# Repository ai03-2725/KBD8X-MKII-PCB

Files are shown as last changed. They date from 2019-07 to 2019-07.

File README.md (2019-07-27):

# KBD8X-MKII-PCB
This is the source for the PCB used in the [KBD8X MKII by KBDfans](https://kbdfans.com/collections/kbd8x-mkii/products/coming-soon-kbd8x-mkii-custom-mechanical-keyboard-kit).  

Please verify the conditions of the [license](https://github.com/ai03-2725/KBD8X-MKII-PCB/blob/master/LICENSE) before using.

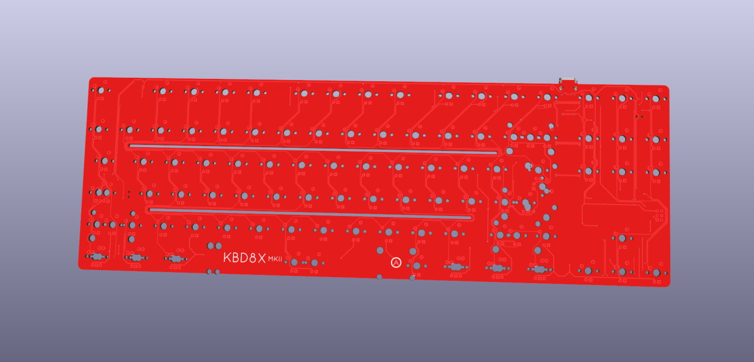
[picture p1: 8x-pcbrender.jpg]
render


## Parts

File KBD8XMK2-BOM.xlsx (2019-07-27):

Component | Description | Part | References | Value | Footprint | Quantity Per PCB
1 | Capacitor, Ceramic, 0603, ≥15V | C_Small | C6 C7 C8 CRGB1 CRGB2 CRGB3 CRGB4 CRGB5 CRGB6 CRGB7 CRGB8 CRGB9 CRGB10 CRGB11 CRGB12 CRGB13 CRGB14 CRGB15 CRGB16 CRGB17 CRGB18 | 0.1uF | C_0603 | 21
2 | Capacitor, Ceramic, 0603, ≥15V | C_Small | C5 | 10uF | C_0603 | 1
3 | Capacitor, Ceramic, 0603, ≥15V | C_Small | C2 | 1uF | C_0603 | 1
4 | Capacitor, Ceramic, 0603, ≥15V | C_Small | C3 C4 | 22pF | C_0603 | 2
5 | Diode, Generic, SOD-123 | D_Small | D1 D2 D3 D4 D5 D6 D7 D8 D9 D10 D11 D12 D13 D14 D17 D18 D19 D20 D21 D22 D23 D24 D25 D26 D27 D28 D29 D30 D31 D35 D36 D37 D38 D39 D40 D41 D42 D43 D44 D45 D46 D47 D48 D52 D53 D54 D55 D56 D57 D58 D59 D60 D61 D62 D63 D65 D66 D67 D68 D69 D70 D71 D72 D73 D74 D75 D76 D77 D78 D81 D82 D84 D85 D86 D87 D90 D91 D92 D93 D94 D95 D96 D97 D99 D100 D101 D108 D111 D112 D113 | SOD-323 | D_SOD-123 | 90
6 | Polyfuse, 1206, 500mA Hold, 1A Trip, ≥15V | Polyfuse_Small | F1 | 500mA | Fuse_SMD1206_Wave | 1
7 | NPN transistor, DSS60601MZ4-13, SOT-223 | Q_NPN_BCE | Q1 | DSS60601MZ4-13 | SOT-223-3_TabPin2 | 1
8 | Resistor, Generic, 0603 | R_Small | R1 R2 R3 R4 R5 R6 R7 R8 R9 R10 R11 R12 R13 R14 R16 R17 R18 R19 R20 R21 R22 R23 R24 R25 R26 R27 R28 R29 R30 R31 R32 R33 R35 R36 R37 R38 R39 R40 R41 R42 R43 R44 R45 R46 R47 R48 R52 R53 R54 R55 R56 R57 R58 R59 R60 R61 R62 R63 R65 R66 R67 R68 R69 R70 R71 R72 R73 R74 R75 R76 R77 R78 R81 R82 R84 R85 R86 R87 R90 R91 R95 R96 R97 R99 R100 R101 R108 R111 R112 R113 RC4 | 1k | R_0603 | 91
9 | Resistor, Generic, 0603 | R_Small | RC5 | 1.5k | R_0603 | 1
10 | Resistor, Generic, 0603 | R_Small | RC3 | 10k | R_0603 | 1
11 | Resistor, Generic, 0603 | R_Small | RC1 RC2 | 22 | R_0603 | 2
12 | Resistor, Generic, 0603 | R_Small | RC6 RC7 | 5k1 | R_0603 | 2
13 | RGB LED, WS2812B, 5050 | WS2812B | RGB1 RGB2 RGB3 RGB4 RGB5 RGB6 RGB7 RGB8 RGB9 RGB10 RGB11 RGB12 RGB13 RGB14 RGB15 RGB16 RGB17 RGB18 | WS2812B | LED_WS2812B-PLCC4 | 18
14 | Push button, 5.2 x 5.2mm | SW_Push | SW1 | SW_Push | SKQG-1155865 | 1
15 | Switch, SPDT, PCM12 | SW_SPDT | SW2 SW3 | SW_SPDT | SW_SPDT_PCM12 | 2
16 | ATmega32U4-MU | ATmega32U4-MU | U1 | ATmega32U4-MU | QFN-44-1EP_7x7mm_Pitch0.5mm | 1
17 | ESD Protection IC, PRTR5V0U2X,215 | PRTR5V0U2X | U2 | PRTR5V0U2X | SOT143B | 1
18 | USB Type-C Connector, HRO TYPE-C-31-M-12 | HRO-TYPE-C-31-M-12 | USB1 | HRO-TYPE-C-31-M-12 | HRO-TYPE-C-31-M-12-Assembly | 1
19 | Crystal, 3.2 x 2.5mm, 16MHz | Crystal_GND24 | Y1 | 16MHz | Crystal_SMD_3225-4pin_3.2x2.5mm | 1
Component Groups: | 19
Component Count: | 239
Fitted Components: | 239
Number of PCBs: | 1
Total components: | 239
Schematic Version:
Schematic Date:
BoM Date: | 2019-04-04 15:30
Schematic Source:
KiCad Version: | Eeschema (5.0.2)-1

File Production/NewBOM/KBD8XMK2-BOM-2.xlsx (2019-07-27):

Comment | Description | Designator | Footprint | Pins | Quantity
0.1uF 20% ≥15V X5R/X7R | Capacitor, Ceramic, 0603 | C6 C7 C8 CRGB1 CRGB2 CRGB3 CRGB4 CRGB5 CRGB6 CRGB7 CRGB8 CRGB9 CRGB10 CRGB11 CRGB12 CRGB13 CRGB14 CRGB15 CRGB16 CRGB17 CRGB18 | C_0603 | 2 | 21
10uF 20% ≥15V X5R/X7R | Capacitor, Ceramic, 0603 | C5 | C_0603 | 2 | 1
1uF 20% ≥15V X5R/X7R | Capacitor, Ceramic, 0603 | C2 | C_0603 | 2 | 1
22pF 5% ≥15V C0G | Capacitor, Ceramic, 0603 | C3 C4 | C_0603 | 2 | 2
Generic | Diode, SOD-123 | D1 D2 D3 D4 D5 D6 D7 D8 D9 D10 D11 D12 D13 D14 D17 D18 D19 D20 D21 D22 D23 D24 D25 D26 D27 D28 D29 D30 D31 D35 D36 D37 D38 D39 D40 D41 D42 D43 D44 D45 D46 D47 D48 D52 D53 D54 D55 D56 D57 D58 D59 D60 D61 D62 D63 D65 D66 D67 D68 D69 D70 D71 D72 D73 D74 D75 D76 D77 D78 D81 D82 D84 D85 D86 D87 D90 D91 D92 D93 D94 D95 D96 D97 D99 D100 D101 D108 D111 D112 D113 | D_SOD-123 | 2 | 90
500mA ≥15V 500mA_Hold 1A_Trip | Polyfuse, 1206 | F1 | Fuse_SMD1206_Wave | 2 | 1
DSS60601MZ4-13 | NPN transistor, SOT-223 | Q1 | SOT-223-3_TabPin2 | 4 | 1
1k 1% | Resistor, Generic, 0603 | R1 R2 R3 R4 R5 R6 R7 R8 R9 R10 R11 R12 R13 R14 R16 R17 R18 R19 R20 R21 R22 R23 R24 R25 R26 R27 R28 R29 R30 R31 R32 R33 R35 R36 R37 R38 R39 R40 R41 R42 R43 R44 R45 R46 R47 R48 R52 R53 R54 R55 R56 R57 R58 R59 R60 R61 R62 R63 R65 R66 R67 R68 R69 R70 R71 R72 R73 R74 R75 R76 R77 R78 R81 R82 R84 R85 R86 R87 R90 R91 R95 R96 R97 R99 R100 R101 R108 R111 R112 R113 RC4 | R_0603 | 2 | 91
1.5k 1% | Resistor, Generic, 0603 | RC5 | R_0603 | 2 | 1
10k 1% | Resistor, Generic, 0603 | RC3 | R_0603 | 2 | 1
22 1% | Resistor, Generic, 0603 | RC1 RC2 | R_0603 | 2 | 2
5.1k 1% | Resistor, Generic, 0603 | RC6 RC7 | R_0603 | 2 | 2
WS2812B | RGB LED, 5050 | RGB1 RGB2 RGB3 RGB4 RGB5 RGB6 RGB7 RGB8 RGB9 RGB10 RGB11 RGB12 RGB13 RGB14 RGB15 RGB16 RGB17 RGB18 | LED_WS2812B-PLCC4 | 4 | 18
SMT 5.2 x 5.2 x 1.5mm | Push button | SW1 | SKQG-1155865 | 4 | 1
SPDT PCM12 | Switch, SPDT | SW2 SW3 | SW_SPDT_PCM12 | 7 | 2
ATmega32U4-MU | ATmega32U4-MU | U1 | QFN-44-1EP_7x7mm_Pitch0.5mm | 45 | 1
PRTR5V0U2X | ESD Protection IC | U2 | SOT143B | 4 | 1
HRO-TYPE-C-31-M-12 | USB Type-C Connector | USB1 | HRO-TYPE-C-31-M-12-Assembly | 16 | 1
16MHz | Crystal, 3.2 x 2.5mm (3225-4) | Y1 | Crystal_SMD_3225-4pin_3.2x2.5mm | 4 | 1

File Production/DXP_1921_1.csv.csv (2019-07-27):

Comment | Description | Designator | Footprint | Pins | Quantity
10nF (103) 10% 50V | 贴片电容 | C1, C2, C3, C4, C5, C6, C7 | LC-0603_C | 2 | 7
1.5nF (152) 10% 50V | 贴片电容 | C8, C9, C10, C11, C22, C23, C31, C32, C34, C35, C36, C37, C38, C39, C40 | LC-0805_C | 2 | 15
100nF (104) ±10% 16V | 贴片电容 | C67, C68, C69, C70, C71, C72, C73, C74, C75, C76, C77, C78, C79, C80, C81, C82, C83, C84, C85, C86, C87, C88, C89, C90, C91, C92, C93, C94, C95, C96, C97, C98, C99, C100, C101, C102, C103, C104, C105, C106, C107 | LC-0402_C | 2 | 41
4.7uH ±10% | 贴片电感 | L1, L4 | LC-0603_L | 2 | 2
47nH | 贴片电感 | L2 | LC-0603_L | 2 | 1
68nH ±5% 0603 | 贴片电感 | L3 | LC-0603_L | 2 | 1
10nH ±5% | 贴片电感 | L16, L17, L18, L19, L20, L21, L22, L23, L24, L25, L26, L27 | LC-0402_L | 2 | 12
22nH ±5% | 贴片电感 | L31 | LC-0603_L | 2 | 1
13KΩ (1302) ±1% | 贴片电阻 | R5, R6, R7, R8, R9, R10, R11, R12, R13, R14, R15, R16, R17, R18, R19, R21, R31, R41, R51, R61 | LC-0603_R | 2 | 20
300Ω (3000) ±1% | 贴片电阻 | R192, R193, R194, R195, R196, R200, R201, R202, R203, R204, R205, R206, R207, R208, R209, R210, R211, R212, R213, R214, R215, R216, R217, R218, R219, R220, R221, R222, R223, R224, R225, R226, R227, R228, R229, R230, R231, R232, R233, R234, R235, R236, R237, R238, R239, R240, R241, R242, R243, R244, R245, R246, R247, R248, R249, R250, R251, R252, R253, R254 | LC-0402_R | 2 | 60

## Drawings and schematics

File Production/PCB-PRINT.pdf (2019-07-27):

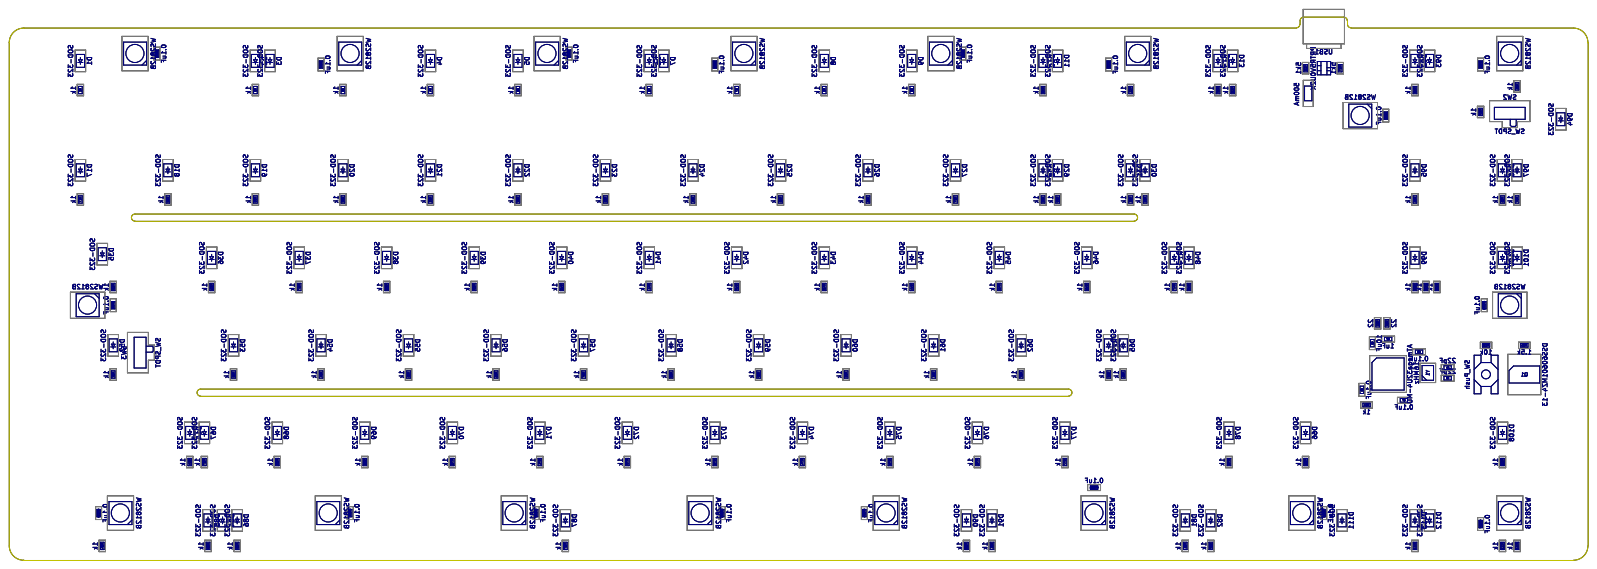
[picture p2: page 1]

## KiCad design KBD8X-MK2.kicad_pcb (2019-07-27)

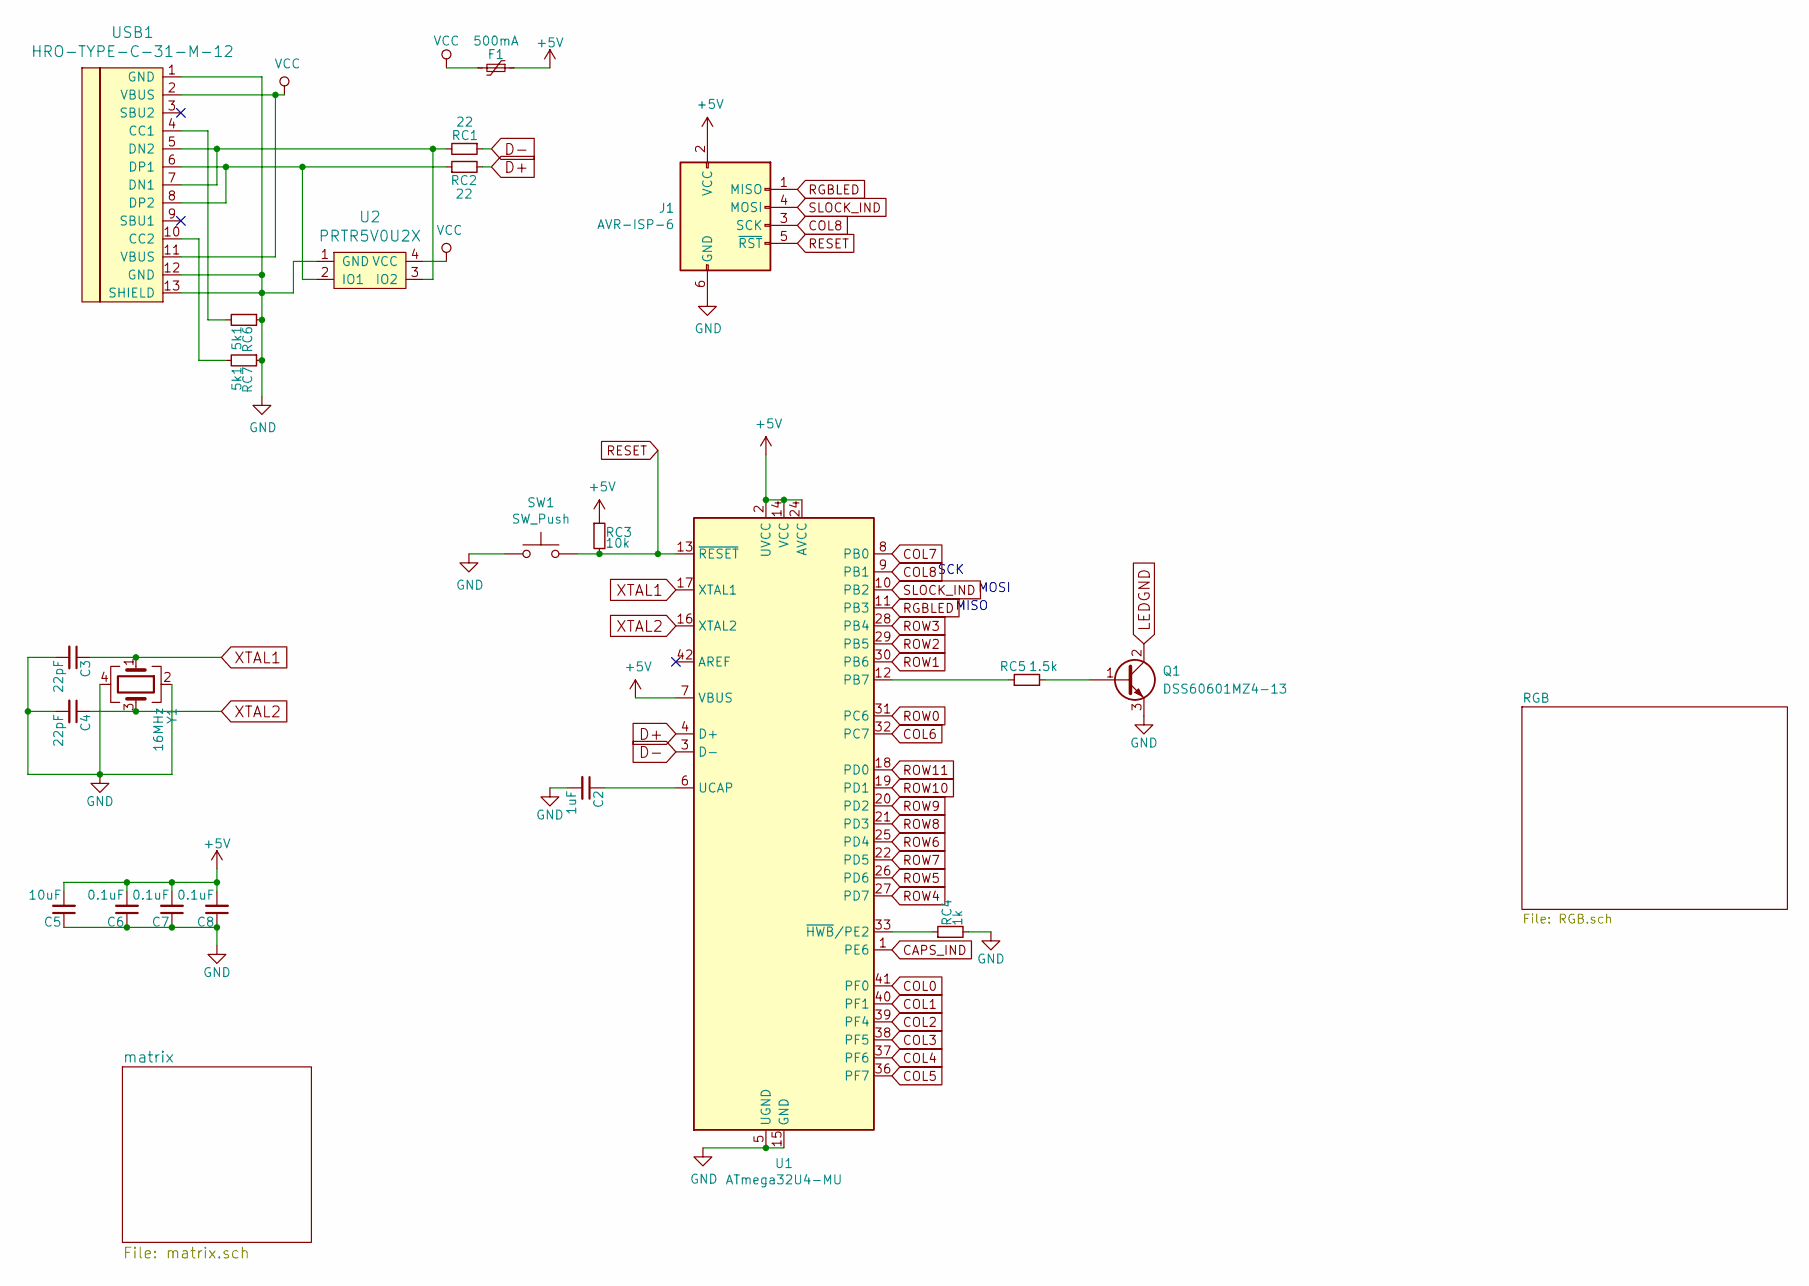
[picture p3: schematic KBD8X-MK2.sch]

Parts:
C2: 1uF; C_0603
C3, C4: 22pF; C_0603
C5: 10uF; C_0603
C6, C7, C8: 0.1uF; C_0603
F1: 500mA; Fuse_SMD1206_Wave
J1: AVR-ISP-6; Reset_Pretty-Mask
Q1: DSS60601MZ4-13; SOT-223-3_TabPin2
RC1, RC2: 22; R_0603
RC3: 10k; R_0603
RC4: 1k; R_0603
RC5: 1.5k; R_0603
RC6, RC7: 5k1; R_0603
SW1: SW_Push; SKQG-1155865
U1: ATmega32U4-MU; QFN-44-1EP_7x7mm_Pitch0.5mm
U2: PRTR5V0U2X; SOT143B
USB1: HRO-TYPE-C-31-M-12; HRO-TYPE-C-31-M-12-Assembly
Y1: 16MHz; Crystal_SMD_3225-4pin_3.2x2.5mm

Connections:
+5V: C5.2, C6.2, C7.2, C8.2, F1.1, J1.2 (VCC), RC3.1, U1.2 (UVCC), U1.7 (VBUS), U1.14 (VCC), U1.24 (AVCC), U1.34 (VCC), U1.44 (AVCC); also elsewhere on the board
CAPS_IND: U1.1 (PE6); also elsewhere on the board
COL0: U1.41 (PF0); also elsewhere on the board
COL1: U1.40 (PF1); also elsewhere on the board
COL2: U1.39 (PF4); also elsewhere on the board
COL3: U1.38 (PF5); also elsewhere on the board
COL4: U1.37 (PF6); also elsewhere on the board
COL5: U1.36 (PF7); also elsewhere on the board
COL6: U1.32 (PC7); also elsewhere on the board
COL7: U1.8 (PB0); also elsewhere on the board
COL8: J1.3 (SCK), U1.9 (PB1); also elsewhere on the board
D+: RC2.2, U1.4 (D+)
D-: RC1.1, U1.3 (D-)
GND: C2.2, C3.2, C4.2, C5.1, C6.1, C7.1, C8.1, J1.6 (GND), Q1.3 (E), RC4.2, RC6.1, RC7.1, SW1.1, U1.5 (UGND), U1.15 (GND), U1.23 (GND), U1.35 (GND), U1.43 (GND), U1.45 (GND), U2.1 (GND), USB1.1 (GND), USB1.12 (GND), USB1.13 (SHIELD), Y1.2, Y1.4; also elsewhere on the board
LEDGND: Q1.2 (C); also elsewhere on the board
unnamed: C2.1, U1.6 (UCAP)
unnamed: Q1.1 (B), RC5.2
unnamed: RC1.2, U2.3 (IO2), USB1.5 (DN2), USB1.7 (DN1)
unnamed: RC2.1, U2.2 (IO1), USB1.6 (DP1), USB1.8 (DP2)
unnamed: RC4.1, U1.33 (~HWB~/PE2)
unnamed: RC5.1, U1.12 (PB7)
unnamed: RC6.2, USB1.4 (CC1)
unnamed: RC7.2, USB1.10 (CC2)
RESET: J1.5 (~RST), RC3.2, SW1.2, U1.13 (~RESET)
RGBLED: J1.1 (MISO), U1.11 (PB3); also elsewhere on the board
ROW0: U1.31 (PC6); also elsewhere on the board
ROW1: U1.30 (PB6); also elsewhere on the board
ROW2: U1.29 (PB5); also elsewhere on the board
ROW3: U1.28 (PB4); also elsewhere on the board
ROW4: U1.27 (PD7); also elsewhere on the board
ROW5: U1.26 (PD6); also elsewhere on the board
ROW6: U1.25 (PD4); also elsewhere on the board
ROW7: U1.22 (PD5); also elsewhere on the board
ROW8: U1.21 (PD3); also elsewhere on the board
ROW9: U1.20 (PD2); also elsewhere on the board
ROW10: U1.19 (PD1); also elsewhere on the board
ROW11: U1.18 (PD0); also elsewhere on the board
SLOCK_IND: J1.4 (MOSI), U1.10 (PB2); also elsewhere on the board
VCC: F1.2, U2.4 (VCC), USB1.2 (VBUS), USB1.11 (VBUS)
XTAL1: C3.1, U1.17 (XTAL1), Y1.1
XTAL2: C4.1, U1.16 (XTAL2), Y1.3

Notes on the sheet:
MOSI
MISO
SCK

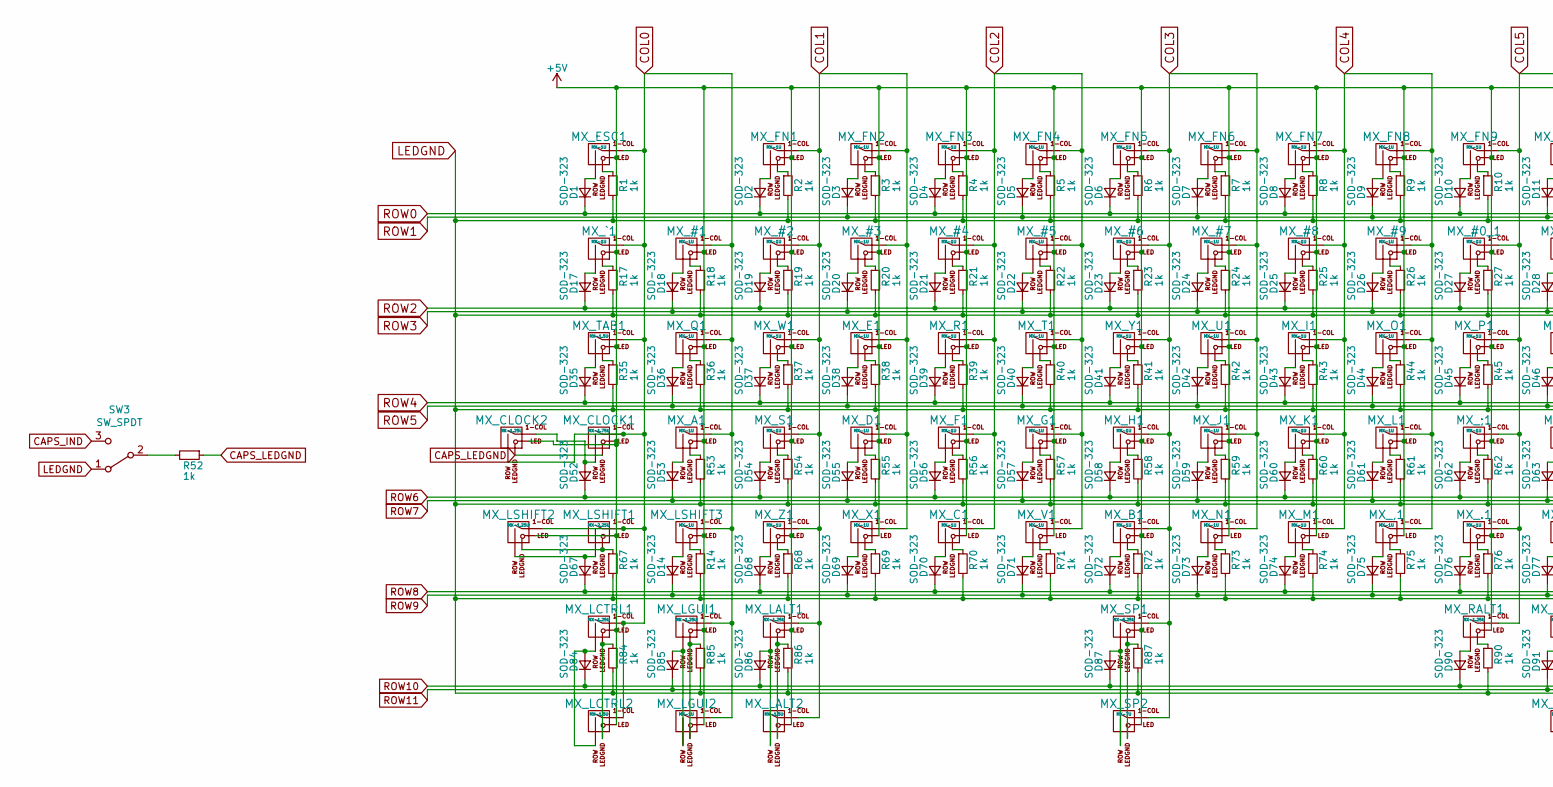
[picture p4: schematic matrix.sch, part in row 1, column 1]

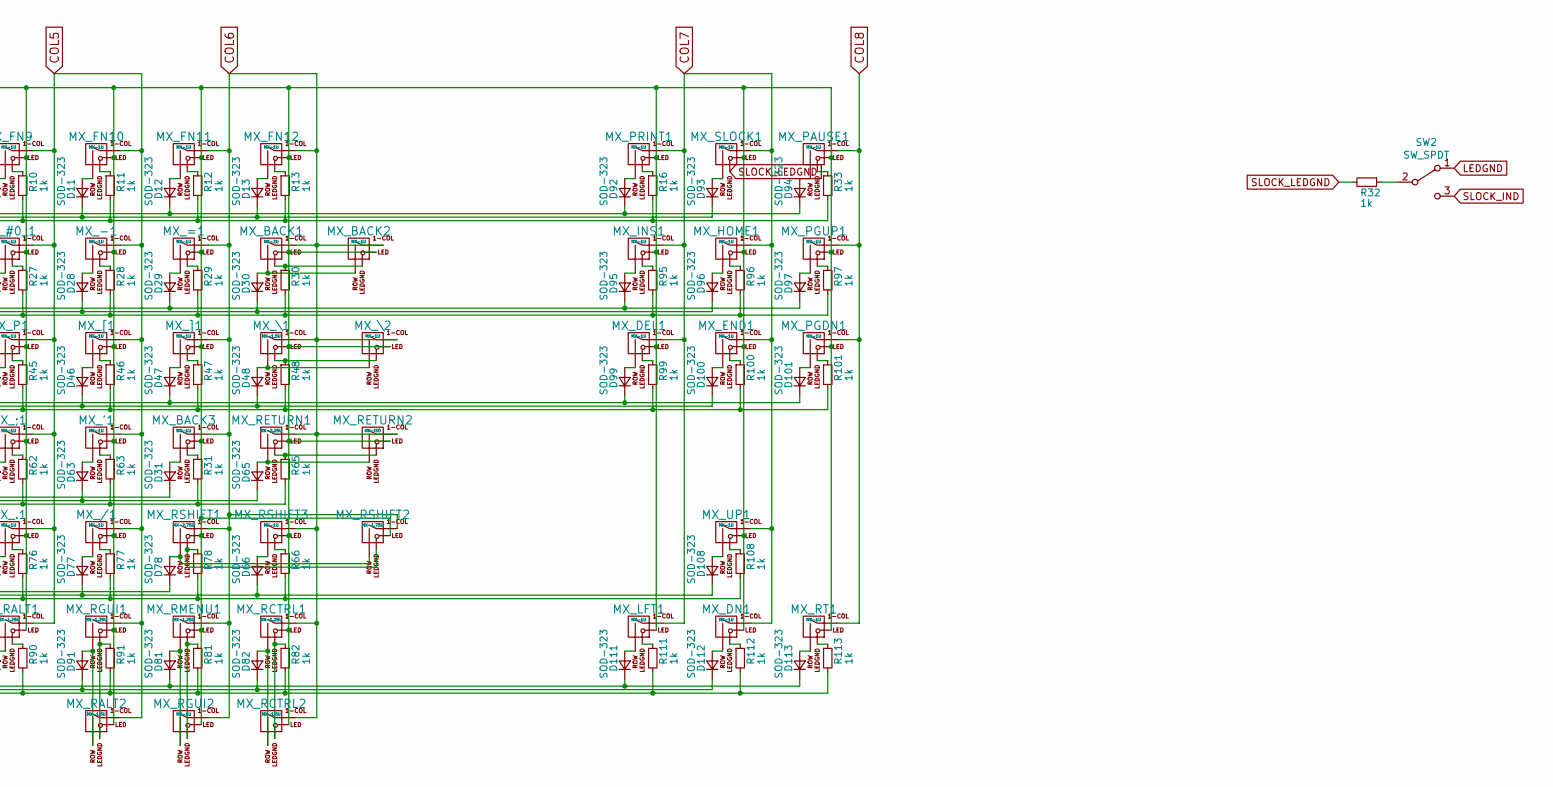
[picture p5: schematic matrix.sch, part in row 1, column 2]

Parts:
D1, D2, D3, D4, D5, D6, D7, D8, D9, D10, D11, D12, D13, D14, D17, D18, D19, D20, D21, D22, D23, D24, D25, D26, D27, D28, D29, D30, D31, D35, D36, D37, D38, D39, D40, D41, D42, D43, D44, D45, D46, D47, D48, D52, D53, D54, D55, D56, D57, D58, D59, D60, D61, D62, D63, D65, D66, D67, D68, D69, D70, D71, D72, D73, D74, D75, D76, D77, D78, D81, D82, D84, D85, D86, D87, D90, D91, D92, D93, D94, D95, D96, D97, D99, D100, D101, D108, D111, D112, D113: SOD-323; D_SOD-123
MX_#0_1, MX_#1, MX_#2, MX_#3, MX_#4, MX_#5, MX_#6, MX_#7, MX_#8, MX_#9: MX-1U; MXOnly-1U
MX_'1: MX-1U; MXOnly-1U
MX_,1: MX-1U; MXOnly-1U
MX_-1: MX-1U; MXOnly-1U
MX_.1: MX-1U; MXOnly-1U
MX_/1: MX-1U; MXOnly-1U
MX_;1: MX-1U; MXOnly-1U
MX_=1: MX-1U; MXOnly-1U
MX_A1: MX-1U; MXOnly-1U
MX_B1: MX-1U; MXOnly-1U
MX_BACK1: MX-2U; MXOnly-2U
MX_BACK2, MX_BACK3: MX-1U; MXOnly-1U
MX_C1: MX-1U; MXOnly-1U
MX_CLOCK1: MX-1.75U; MXOnly-1.75U
MX_CLOCK2: MX-1.25U; MXOnly-1.25U-FLIPPED
MX_D1: MX-1U; MXOnly-1U
MX_DEL1: MX-1U; MXOnly-1U
MX_DN1: MX-1U; MXOnly-1U
MX_E1: MX-1U; MXOnly-1U
MX_END1: MX-1U; MXOnly-1U
MX_ESC1: MX-1U; MXOnly-1U
MX_F1: MX-1U; MXOnly-1U
MX_FN1, MX_FN2, MX_FN3, MX_FN4, MX_FN5, MX_FN6, MX_FN7, MX_FN8, MX_FN9, MX_FN10, MX_FN11, MX_FN12: MX-1U; MXOnly-1U
MX_G1: MX-1U; MXOnly-1U
MX_H1: MX-1U; MXOnly-1U
MX_HOME1: MX-1U; MXOnly-1U
MX_I1: MX-1U; MXOnly-1U
MX_INS1: MX-1U; MXOnly-1U
MX_J1: MX-1U; MXOnly-1U
MX_K1: MX-1U; MXOnly-1U
MX_L1: MX-1U; MXOnly-1U
MX_LALT1: MX-1.25U; MXOnly-1.25U
MX_LALT2: MX-1.5U; MXOnly-1.5U-FLIPPED
MX_LCTRL1: MX-1.25U; MXOnly-1.25U
MX_LCTRL2: MX-1.5U; MXOnly-1.5U-FLIPPED
MX_LFT1: MX-1U; MXOnly-1U
MX_LGUI1: MX-1.25U; MXOnly-1.25U
MX_LGUI2: MX-1U; MXOnly-1U-FLIPPED
MX_LSHIFT1: MX-2.25U; MXOnly-2.25U
MX_LSHIFT2: MX-1.25U; MXOnly-1.25U
MX_LSHIFT3: MX-1U; MXOnly-1U
MX_M1: MX-1U; MXOnly-1U
MX_N1: MX-1U; MXOnly-1U
MX_O1: MX-1U; MXOnly-1U
MX_P1: MX-1U; MXOnly-1U
MX_PAUSE1: MX-1U; MXOnly-1U
MX_PGDN1: MX-1U; MXOnly-1U
MX_PGUP1: MX-1U; MXOnly-1U
MX_PRINT1: MX-1U; MXOnly-1U
MX_Q1: MX-1U; MXOnly-1U
MX_R1: MX-1U; MXOnly-1U
MX_RALT1: MX-1.25U; MXOnly-1.25U
MX_RALT2: MX-1.5U; MXOnly-1.5U
MX_RCTRL1: MX-1.25U; MXOnly-1.25U-FLIPPED
MX_RCTRL2: MX-1.5U; MXOnly-1.5U
MX_RETURN1: MX-2.25U; MXOnly-2.25U
MX_RETURN2: MX-ISO; MXOnly-ISO-ROTATED-ReversedStabilizers
MX_RGUI1: MX-1.25U; MXOnly-1.25U-FLIPPED
MX_RGUI2: MX-1U; MXOnly-1U
MX_RMENU1: MX-1.25U; MXOnly-1.25U-FLIPPED
MX_RSHIFT1: MX-2.75U; MXOnly-2.75U
MX_RSHIFT2: MX-1.75U; MXOnly-1.75U
MX_RSHIFT3: MX-1U; MXOnly-1U
MX_RT1: MX-1U; MXOnly-1U
MX_S1: MX-1U; MXOnly-1U
MX_SLOCK1: MX-1U; MXOnly-1U
MX_SP1: MX-6.25U; MXOnly-6.25U-ReversedStabilizers
MX_SP2: MX-7U; MXOnly-7U-ReversedStabilizers
MX_T1: MX-1U; MXOnly-1U
MX_TAB1: MX-1.5U; MXOnly-1.5U
MX_U1: MX-1U; MXOnly-1U
MX_UP1: MX-1U; MXOnly-1U
MX_V1: MX-1U; MXOnly-1U
MX_W1: MX-1U; MXOnly-1U
MX_X1: MX-1U; MXOnly-1U
MX_Y1: MX-1U; MXOnly-1U
MX_Z1: MX-1U; MXOnly-1U
MX_[1: MX-1U; MXOnly-1U
MX_\1: MX-1.5U; MXOnly-1.5U
MX_\2: MX-1U; MXOnly-1U
MX_]1: MX-1U; MXOnly-1U
MX_`1: MX-1U; MXOnly-1U
R1, R2, R3, R4, R5, R6, R7, R8, R9, R10, R11, R12, R13, R14, R16, R17, R18, R19, R20, R21, R22, R23, R24, R25, R26, R27, R28, R29, R30, R31, R32, R33, R35, R36, R37, R38, R39, R40, R41, R42, R43, R44, R45, R46, R47, R48, R52, R53, R54, R55, R56, R57, R58, R59, R60, R61, R62, R63, R65, R66, R67, R68, R69, R70, R71, R72, R73, R74, R75, R76, R77, R78, R81, R82, R84, R85, R86, R87, R90, R91, R95, R96, R97, R99, R100, R101, R108, R111, R112, R113: 1k; R_0603
SW2, SW3: SW_SPDT; SW_SPDT_PCM12

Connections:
+5V: MX_#0_1.3 (LED), MX_#1.3 (LED), MX_#2.3 (LED), MX_#3.3 (LED), MX_#4.3 (LED), MX_#5.3 (LED), MX_#6.3 (LED), MX_#7.3 (LED), MX_#8.3 (LED), MX_#9.3 (LED), MX_'1.3 (LED), MX_,1.3 (LED), MX_-1.3 (LED), MX_.1.3 (LED), MX_/1.3 (LED), MX_;1.3 (LED), MX_=1.3 (LED), MX_A1.3 (LED), MX_B1.3 (LED), MX_BACK1.3 (LED), MX_BACK2.3 (LED), MX_BACK3.3 (LED), MX_C1.3 (LED), MX_CLOCK1.3 (LED), MX_CLOCK2.3 (LED), MX_D1.3 (LED), MX_DEL1.3 (LED), MX_DN1.3 (LED), MX_E1.3 (LED), MX_END1.3 (LED), MX_ESC1.3 (LED), MX_F1.3 (LED), MX_FN1.3 (LED), MX_FN2.3 (LED), MX_FN3.3 (LED), MX_FN4.3 (LED), MX_FN5.3 (LED), MX_FN6.3 (LED), MX_FN7.3 (LED), MX_FN8.3 (LED), MX_FN9.3 (LED), MX_FN10.3 (LED), MX_FN11.3 (LED), MX_FN12.3 (LED), MX_G1.3 (LED), MX_H1.3 (LED), MX_HOME1.3 (LED), MX_I1.3 (LED), MX_INS1.3 (LED), MX_J1.3 (LED), MX_K1.3 (LED), MX_L1.3 (LED), MX_LALT1.3 (LED), MX_LALT2.3 (LED), MX_LCTRL1.3 (LED), MX_LCTRL2.3 (LED), MX_LFT1.3 (LED), MX_LGUI1.3 (LED), MX_LGUI2.3 (LED), MX_LSHIFT1.3 (LED), MX_LSHIFT2.3 (LED), MX_LSHIFT3.3 (LED), MX_M1.3 (LED), MX_N1.3 (LED), MX_O1.3 (LED), MX_P1.3 (LED), MX_PAUSE1.3 (LED), MX_PGDN1.3 (LED), MX_PGUP1.3 (LED), MX_PRINT1.3 (LED), MX_Q1.3 (LED), MX_R1.3 (LED), MX_RALT1.3 (LED), MX_RALT2.3 (LED), MX_RCTRL1.3 (LED), MX_RCTRL2.3 (LED), MX_RETURN1.3 (LED), MX_RETURN2.3 (LED), MX_RGUI1.3 (LED), MX_RGUI2.3 (LED), MX_RMENU1.3 (LED), MX_RSHIFT1.3 (LED), MX_RSHIFT2.3 (LED), MX_RSHIFT3.3 (LED), MX_RT1.3 (LED), MX_S1.3 (LED), MX_SLOCK1.3 (LED), MX_SP1.3 (LED), MX_SP2.3 (LED), MX_T1.3 (LED), MX_TAB1.3 (LED), MX_U1.3 (LED), MX_UP1.3 (LED), MX_V1.3 (LED), MX_W1.3 (LED), MX_X1.3 (LED), MX_Y1.3 (LED), MX_Z1.3 (LED), MX_[1.3 (LED), MX_\1.3 (LED), MX_\2.3 (LED), MX_]1.3 (LED), MX_`1.3 (LED); also elsewhere on the board
CAPS_IND: SW3.3 (C); also elsewhere on the board
CAPS_LEDGND: MX_CLOCK1.4 (LEDGND), MX_CLOCK2.4 (LEDGND), R52.1
COL0: MX_#1.1 (COL), MX_A1.1 (COL), MX_CLOCK1.1 (COL), MX_CLOCK2.2 (ROW), MX_ESC1.1 (COL), MX_LCTRL1.1 (COL), MX_LCTRL2.1 (COL), MX_LGUI1.1 (COL), MX_LGUI2.1 (COL), MX_LSHIFT1.1 (COL), MX_LSHIFT2.1 (COL), MX_LSHIFT3.1 (COL), MX_Q1.1 (COL), MX_TAB1.1 (COL), MX_`1.1 (COL); also elsewhere on the board
COL1: MX_#2.1 (COL), MX_#3.1 (COL), MX_D1.1 (COL), MX_E1.1 (COL), MX_FN1.1 (COL), MX_FN2.1 (COL), MX_LALT1.1 (COL), MX_LALT2.1 (COL), MX_S1.1 (COL), MX_W1.1 (COL), MX_X1.1 (COL), MX_Z1.1 (COL); also elsewhere on the board
COL2: MX_#4.1 (COL), MX_#5.1 (COL), MX_C1.1 (COL), MX_F1.1 (COL), MX_FN3.1 (COL), MX_FN4.1 (COL), MX_G1.1 (COL), MX_R1.1 (COL), MX_T1.1 (COL), MX_V1.1 (COL); also elsewhere on the board
COL3: MX_#6.1 (COL), MX_#7.1 (COL), MX_B1.1 (COL), MX_FN5.1 (COL), MX_FN6.1 (COL), MX_H1.1 (COL), MX_J1.1 (COL), MX_N1.1 (COL), MX_SP1.1 (COL), MX_SP2.1 (COL), MX_U1.1 (COL), MX_Y1.1 (COL); also elsewhere on the board
COL4: MX_#8.1 (COL), MX_#9.1 (COL), MX_,1.1 (COL), MX_FN7.1 (COL), MX_FN8.1 (COL), MX_I1.1 (COL), MX_K1.1 (COL), MX_L1.1 (COL), MX_M1.1 (COL), MX_O1.1 (COL); also elsewhere on the board
COL5: MX_#0_1.1 (COL), MX_'1.1 (COL), MX_-1.1 (COL), MX_.1.1 (COL), MX_/1.1 (COL), MX_;1.1 (COL), MX_FN9.1 (COL), MX_FN10.1 (COL), MX_P1.1 (COL), MX_RALT1.1 (COL), MX_RALT2.1 (COL), MX_RGUI1.1 (COL), MX_[1.1 (COL); also elsewhere on the board
COL6: MX_=1.1 (COL), MX_BACK1.1 (COL), MX_BACK2.1 (COL), MX_BACK3.1 (COL), MX_FN11.1 (COL), MX_FN12.1 (COL), MX_RCTRL1.1 (COL), MX_RCTRL2.1 (COL), MX_RETURN1.1 (COL), MX_RETURN2.1 (COL), MX_RGUI2.1 (COL), MX_RMENU1.1 (COL), MX_RSHIFT1.1 (COL), MX_RSHIFT2.1 (COL), MX_RSHIFT3.1 (COL), MX_\1.1 (COL), MX_\2.1 (COL), MX_]1.1 (COL); also elsewhere on the board
COL7: MX_DEL1.1 (COL), MX_DN1.1 (COL), MX_END1.1 (COL), MX_HOME1.1 (COL), MX_INS1.1 (COL), MX_LFT1.1 (COL), MX_PRINT1.1 (COL), MX_SLOCK1.1 (COL), MX_UP1.1 (COL); also elsewhere on the board
COL8: MX_PAUSE1.1 (COL), MX_PGDN1.1 (COL), MX_PGUP1.1 (COL), MX_RT1.1 (COL); also elsewhere on the board
LEDGND: R1.2, R2.2, R3.2, R4.2, R5.2, R6.2, R7.2, R8.2, R9.2, R10.2, R11.2, R12.2, R13.2, R14.2, R16.2, R17.2, R18.2, R19.2, R20.2, R21.2, R22.2, R23.2, R24.2, R25.2, R26.2, R27.2, R28.2, R29.2, R30.2, R31.2, R33.2, R35.2, R36.2, R37.2, R38.2, R39.2, R40.2, R41.2, R42.2, R43.2, R44.2, R45.2, R46.2, R47.2, R48.2, R53.2, R54.2, R55.2, R56.2, R57.2, R58.2, R59.2, R60.2, R61.2, R62.2, R63.2, R65.2, R66.2, R67.2, R68.2, R69.2, R70.2, R71.2, R72.2, R73.2, R74.2, R75.2, R76.2, R77.2, R78.2, R81.2, R82.2, R84.2, R85.2, R86.2, R87.2, R90.2, R91.2, R95.2, R96.2, R97.2, R99.2, R100.2, R101.2, R108.2, R111.2, R112.2, R113.2, SW2.1 (A), SW3.1 (A); also elsewhere on the board
unnamed: D1.2 (A), MX_ESC1.2 (ROW)
unnamed: D2.2 (A), MX_FN1.2 (ROW)
unnamed: D3.2 (A), MX_FN2.2 (ROW)
unnamed: D4.2 (A), MX_FN3.2 (ROW)
unnamed: D5.2 (A), MX_FN4.2 (ROW)
unnamed: D6.2 (A), MX_FN5.2 (ROW)
unnamed: D7.2 (A), MX_FN6.2 (ROW)
unnamed: D8.2 (A), MX_FN7.2 (ROW)
unnamed: D9.2 (A), MX_FN8.2 (ROW)
unnamed: D10.2 (A), MX_FN9.2 (ROW)
unnamed: D11.2 (A), MX_FN10.2 (ROW)
unnamed: D12.2 (A), MX_FN11.2 (ROW)
unnamed: D13.2 (A), MX_FN12.2 (ROW)
unnamed: D14.2 (A), MX_LSHIFT3.2 (ROW)
unnamed: D17.2 (A), MX_`1.2 (ROW)
unnamed: D18.2 (A), MX_#1.2 (ROW)
unnamed: D19.2 (A), MX_#2.2 (ROW)
unnamed: D20.2 (A), MX_#3.2 (ROW)
unnamed: D21.2 (A), MX_#4.2 (ROW)
unnamed: D22.2 (A), MX_#5.2 (ROW)
unnamed: D23.2 (A), MX_#6.2 (ROW)
unnamed: D24.2 (A), MX_#7.2 (ROW)
unnamed: D25.2 (A), MX_#8.2 (ROW)
unnamed: D26.2 (A), MX_#9.2 (ROW)
unnamed: D27.2 (A), MX_#0_1.2 (ROW)
unnamed: D28.2 (A), MX_-1.2 (ROW)
unnamed: D29.2 (A), MX_=1.2 (ROW)
unnamed: D30.2 (A), MX_BACK1.2 (ROW), MX_BACK2.2 (ROW)
unnamed: D31.2 (A), MX_BACK3.2 (ROW)
unnamed: D35.2 (A), MX_TAB1.2 (ROW)
unnamed: D36.2 (A), MX_Q1.2 (ROW)
unnamed: D37.2 (A), MX_W1.2 (ROW)
unnamed: D38.2 (A), MX_E1.2 (ROW)
unnamed: D39.2 (A), MX_R1.2 (ROW)
unnamed: D40.2 (A), MX_T1.2 (ROW)
unnamed: D41.2 (A), MX_Y1.2 (ROW)
unnamed: D42.2 (A), MX_U1.2 (ROW)
unnamed: D43.2 (A), MX_I1.2 (ROW)
unnamed: D44.2 (A), MX_O1.2 (ROW)
unnamed: D45.2 (A), MX_P1.2 (ROW)
unnamed: D46.2 (A), MX_[1.2 (ROW)
unnamed: D47.2 (A), MX_]1.2 (ROW)
unnamed: D48.2 (A), MX_\1.2 (ROW), MX_\2.2 (ROW)
unnamed: D52.2 (A), MX_CLOCK1.2 (ROW), MX_CLOCK2.1 (COL)
unnamed: D53.2 (A), MX_A1.2 (ROW)
unnamed: D54.2 (A), MX_S1.2 (ROW)
unnamed: D55.2 (A), MX_D1.2 (ROW)
unnamed: D56.2 (A), MX_F1.2 (ROW)
unnamed: D57.2 (A), MX_G1.2 (ROW)
unnamed: D58.2 (A), MX_H1.2 (ROW)
unnamed: D59.2 (A), MX_J1.2 (ROW)
unnamed: D60.2 (A), MX_K1.2 (ROW)
unnamed: D61.2 (A), MX_L1.2 (ROW)
unnamed: D62.2 (A), MX_;1.2 (ROW)
unnamed: D63.2 (A), MX_'1.2 (ROW)
unnamed: D65.2 (A), MX_RETURN1.2 (ROW), MX_RETURN2.2 (ROW)
unnamed: D66.2 (A), MX_RSHIFT3.2 (ROW)
unnamed: D67.2 (A), MX_LSHIFT1.2 (ROW), MX_LSHIFT2.2 (ROW)
unnamed: D68.2 (A), MX_Z1.2 (ROW)
unnamed: D69.2 (A), MX_X1.2 (ROW)
unnamed: D70.2 (A), MX_C1.2 (ROW)
unnamed: D71.2 (A), MX_V1.2 (ROW)
unnamed: D72.2 (A), MX_B1.2 (ROW)
unnamed: D73.2 (A), MX_N1.2 (ROW)
unnamed: D74.2 (A), MX_M1.2 (ROW)
unnamed: D75.2 (A), MX_,1.2 (ROW)
unnamed: D76.2 (A), MX_.1.2 (ROW)
unnamed: D77.2 (A), MX_/1.2 (ROW)
unnamed: D78.2 (A), MX_RSHIFT1.2 (ROW), MX_RSHIFT2.2 (ROW)
unnamed: D81.2 (A), MX_RGUI2.2 (ROW), MX_RMENU1.2 (ROW)
unnamed: D82.2 (A), MX_RCTRL1.2 (ROW), MX_RCTRL2.2 (ROW)
unnamed: D84.2 (A), MX_LCTRL1.2 (ROW), MX_LCTRL2.2 (ROW)
unnamed: D85.2 (A), MX_LGUI1.2 (ROW), MX_LGUI2.2 (ROW)
unnamed: D86.2 (A), MX_LALT1.2 (ROW), MX_LALT2.2 (ROW)
unnamed: D87.2 (A), MX_SP1.2 (ROW), MX_SP2.2 (ROW)
unnamed: D90.2 (A), MX_RALT1.2 (ROW)
unnamed: D91.2 (A), MX_RALT2.2 (ROW), MX_RGUI1.2 (ROW)
unnamed: D92.2 (A), MX_PRINT1.2 (ROW)
unnamed: D93.2 (A), MX_SLOCK1.2 (ROW)
unnamed: D94.2 (A), MX_PAUSE1.2 (ROW)
unnamed: D95.2 (A), MX_INS1.2 (ROW)
unnamed: D96.2 (A), MX_HOME1.2 (ROW)
unnamed: D97.2 (A), MX_PGUP1.2 (ROW)
unnamed: D99.2 (A), MX_DEL1.2 (ROW)
unnamed: D100.2 (A), MX_END1.2 (ROW)
unnamed: D101.2 (A), MX_PGDN1.2 (ROW)
unnamed: D108.2 (A), MX_UP1.2 (ROW)
unnamed: D111.2 (A), MX_LFT1.2 (ROW)
unnamed: D112.2 (A), MX_DN1.2 (ROW)
unnamed: D113.2 (A), MX_RT1.2 (ROW)
unnamed: MX_#0_1.4 (LEDGND), R27.1
unnamed: MX_#1.4 (LEDGND), R18.1
unnamed: MX_#2.4 (LEDGND), R19.1
unnamed: MX_#3.4 (LEDGND), R20.1
unnamed: MX_#4.4 (LEDGND), R21.1
unnamed: MX_#5.4 (LEDGND), R22.1
unnamed: MX_#6.4 (LEDGND), R23.1
unnamed: MX_#7.4 (LEDGND), R24.1
unnamed: MX_#8.4 (LEDGND), R25.1
unnamed: MX_#9.4 (LEDGND), R26.1
unnamed: MX_'1.4 (LEDGND), R63.1
unnamed: MX_,1.4 (LEDGND), R75.1
unnamed: MX_-1.4 (LEDGND), R28.1
unnamed: MX_.1.4 (LEDGND), R76.1
unnamed: MX_/1.4 (LEDGND), R77.1
unnamed: MX_;1.4 (LEDGND), R62.1
unnamed: MX_=1.4 (LEDGND), R29.1
unnamed: MX_A1.4 (LEDGND), R53.1
unnamed: MX_B1.4 (LEDGND), R72.1
unnamed: MX_BACK1.4 (LEDGND), MX_BACK2.4 (LEDGND), R30.1
unnamed: MX_BACK3.4 (LEDGND), R31.1
unnamed: MX_C1.4 (LEDGND), R70.1
unnamed: MX_D1.4 (LEDGND), R55.1
unnamed: MX_DEL1.4 (LEDGND), R99.1
unnamed: MX_DN1.4 (LEDGND), R112.1
unnamed: MX_E1.4 (LEDGND), R38.1
unnamed: MX_END1.4 (LEDGND), R100.1
unnamed: MX_ESC1.4 (LEDGND), R1.1
unnamed: MX_F1.4 (LEDGND), R56.1
unnamed: MX_FN1.4 (LEDGND), R2.1
unnamed: MX_FN2.4 (LEDGND), R3.1
unnamed: MX_FN3.4 (LEDGND), R4.1
unnamed: MX_FN4.4 (LEDGND), R5.1
unnamed: MX_FN5.4 (LEDGND), R6.1
unnamed: MX_FN6.4 (LEDGND), R7.1
unnamed: MX_FN7.4 (LEDGND), R8.1
unnamed: MX_FN8.4 (LEDGND), R9.1
unnamed: MX_FN9.4 (LEDGND), R10.1
unnamed: MX_FN10.4 (LEDGND), R11.1
unnamed: MX_FN11.4 (LEDGND), R12.1
unnamed: MX_FN12.4 (LEDGND), R13.1
unnamed: MX_G1.4 (LEDGND), R57.1
unnamed: MX_H1.4 (LEDGND), R58.1
unnamed: MX_HOME1.4 (LEDGND), R96.1
unnamed: MX_I1.4 (LEDGND), R43.1
unnamed: MX_INS1.4 (LEDGND), R95.1
unnamed: MX_J1.4 (LEDGND), R59.1
unnamed: MX_K1.4 (LEDGND), R60.1
unnamed: MX_L1.4 (LEDGND), R61.1
unnamed: MX_LALT1.4 (LEDGND), MX_LALT2.4 (LEDGND), R86.1
unnamed: MX_LCTRL1.4 (LEDGND), MX_LCTRL2.4 (LEDGND), R84.1
unnamed: MX_LFT1.4 (LEDGND), R111.1
unnamed: MX_LGUI1.4 (LEDGND), MX_LGUI2.4 (LEDGND), R85.1
unnamed: MX_LSHIFT1.4 (LEDGND), MX_LSHIFT2.4 (LEDGND), R67.1
unnamed: MX_LSHIFT3.4 (LEDGND), R14.1
unnamed: MX_M1.4 (LEDGND), R74.1
unnamed: MX_N1.4 (LEDGND), R73.1
unnamed: MX_O1.4 (LEDGND), R44.1
unnamed: MX_P1.4 (LEDGND), R45.1
unnamed: MX_PAUSE1.4 (LEDGND), R33.1
unnamed: MX_PGDN1.4 (LEDGND), R101.1
unnamed: MX_PGUP1.4 (LEDGND), R97.1
unnamed: MX_PRINT1.4 (LEDGND), R16.1
unnamed: MX_Q1.4 (LEDGND), R36.1
unnamed: MX_R1.4 (LEDGND), R39.1
unnamed: MX_RALT1.4 (LEDGND), R90.1
unnamed: MX_RALT2.4 (LEDGND), MX_RGUI1.4 (LEDGND), R91.1
unnamed: MX_RCTRL1.4 (LEDGND), MX_RCTRL2.4 (LEDGND), R82.1
unnamed: MX_RETURN1.4 (LEDGND), MX_RETURN2.4 (LEDGND), R65.1
unnamed: MX_RGUI2.4 (LEDGND), MX_RMENU1.4 (LEDGND), R81.1
unnamed: MX_RSHIFT1.4 (LEDGND), MX_RSHIFT2.4 (LEDGND), R78.1
unnamed: MX_RSHIFT3.4 (LEDGND), R66.1
unnamed: MX_RT1.4 (LEDGND), R113.1
unnamed: MX_S1.4 (LEDGND), R54.1
unnamed: MX_SP1.4 (LEDGND), MX_SP2.4 (LEDGND), R87.1
unnamed: MX_T1.4 (LEDGND), R40.1
unnamed: MX_TAB1.4 (LEDGND), R35.1
unnamed: MX_U1.4 (LEDGND), R42.1
unnamed: MX_UP1.4 (LEDGND), R108.1
unnamed: MX_V1.4 (LEDGND), R71.1
unnamed: MX_W1.4 (LEDGND), R37.1
unnamed: MX_X1.4 (LEDGND), R69.1
unnamed: MX_Y1.4 (LEDGND), R41.1
unnamed: MX_Z1.4 (LEDGND), R68.1
unnamed: MX_[1.4 (LEDGND), R46.1
unnamed: MX_\1.4 (LEDGND), MX_\2.4 (LEDGND), R48.1
unnamed: MX_]1.4 (LEDGND), R47.1
unnamed: MX_`1.4 (LEDGND), R17.1
unnamed: R32.1, SW2.2 (B)
unnamed: R52.2, SW3.2 (B)
ROW0: D1.1 (K), D2.1 (K), D4.1 (K), D6.1 (K), D8.1 (K), D10.1 (K), D12.1 (K), D92.1 (K), D94.1 (K); also elsewhere on the board
ROW1: D3.1 (K), D5.1 (K), D7.1 (K), D9.1 (K), D11.1 (K), D13.1 (K), D93.1 (K); also elsewhere on the board
ROW2: D17.1 (K), D19.1 (K), D21.1 (K), D23.1 (K), D25.1 (K), D27.1 (K), D29.1 (K), D95.1 (K), D97.1 (K); also elsewhere on the board
ROW3: D18.1 (K), D20.1 (K), D22.1 (K), D24.1 (K), D26.1 (K), D28.1 (K), D30.1 (K), D96.1 (K); also elsewhere on the board
ROW4: D35.1 (K), D37.1 (K), D39.1 (K), D41.1 (K), D43.1 (K), D45.1 (K), D47.1 (K), D99.1 (K), D101.1 (K); also elsewhere on the board
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

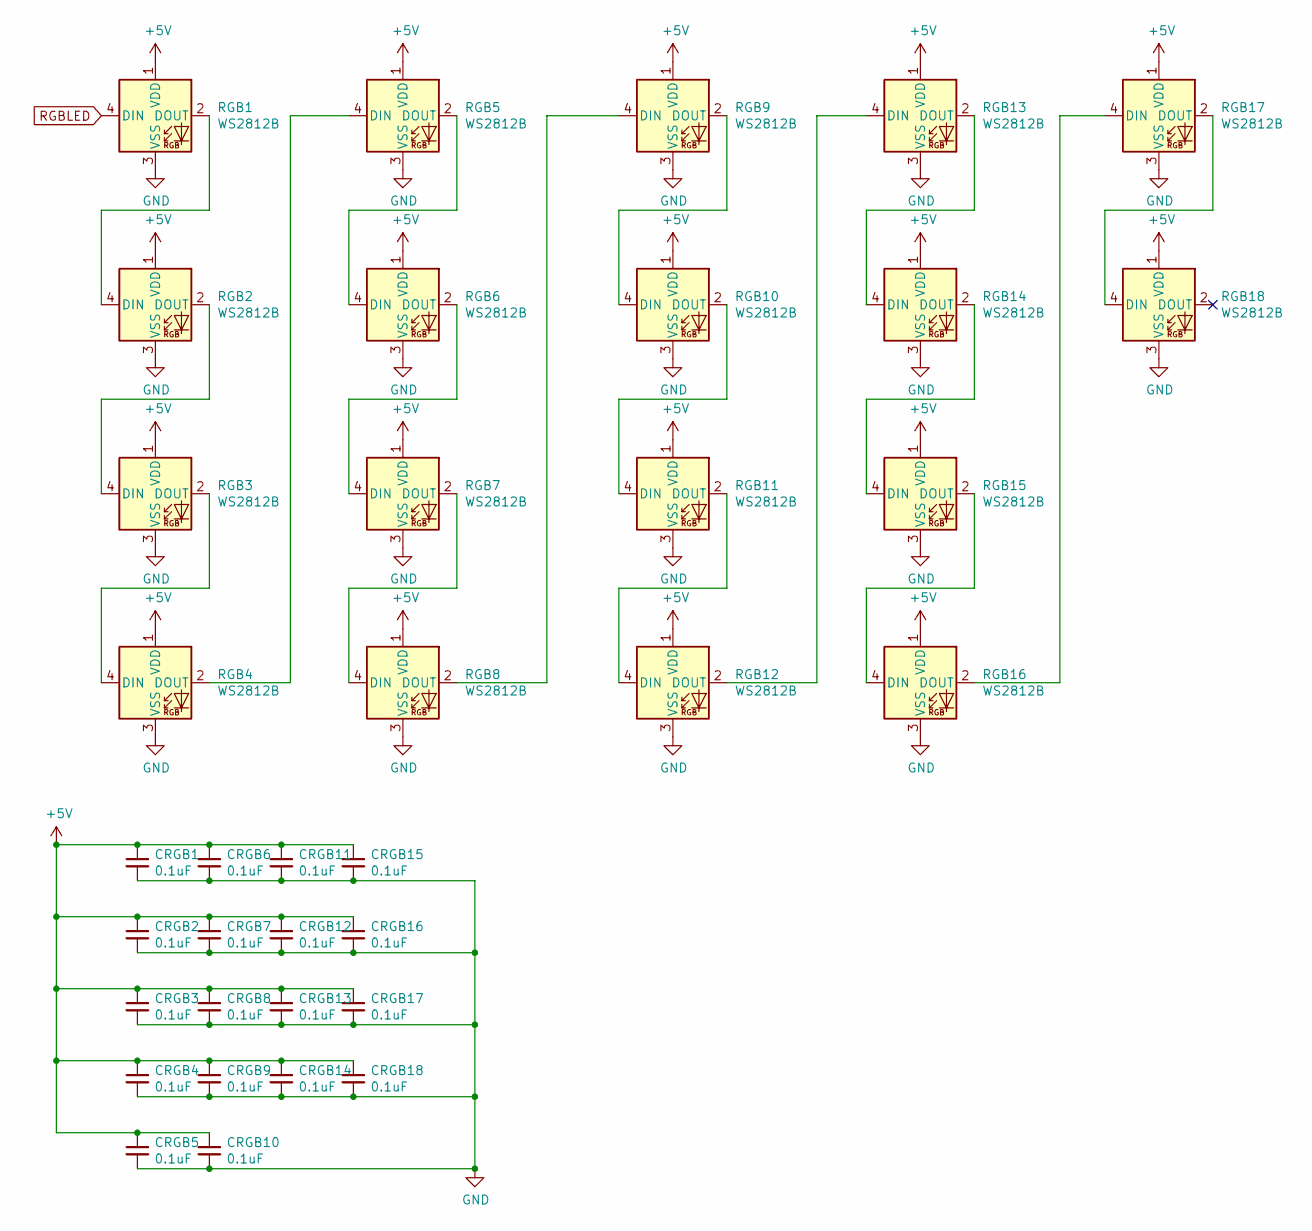
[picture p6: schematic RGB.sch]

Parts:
CRGB1, CRGB2, CRGB3, CRGB4, CRGB5, CRGB6, CRGB7, CRGB8, CRGB9, CRGB10, CRGB11, CRGB12, CRGB13, CRGB14, CRGB15, CRGB16, CRGB17, CRGB18: 0.1uF; C_0603
RGB1, RGB2, RGB3, RGB4, RGB5, RGB6, RGB7, RGB8, RGB9, RGB10, RGB11, RGB12, RGB13, RGB14, RGB15, RGB16, RGB17, RGB18: WS2812B; LED_WS2812B-PLCC4

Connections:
+5V: CRGB1.1, CRGB2.1, CRGB3.1, CRGB4.1, CRGB5.1, CRGB6.1, CRGB7.1, CRGB8.1, CRGB9.1, CRGB10.1, CRGB11.1, CRGB12.1, CRGB13.1, CRGB14.1, CRGB15.1, CRGB16.1, CRGB17.1, CRGB18.1, RGB1.1 (VDD), RGB2.1 (VDD), RGB3.1 (VDD), RGB4.1 (VDD), RGB5.1 (VDD), RGB6.1 (VDD), RGB7.1 (VDD), RGB8.1 (VDD), RGB9.1 (VDD), RGB10.1 (VDD), RGB11.1 (VDD), RGB12.1 (VDD), RGB13.1 (VDD), RGB14.1 (VDD), RGB15.1 (VDD), RGB16.1 (VDD), RGB17.1 (VDD), RGB18.1 (VDD); also elsewhere on the board
GND: CRGB1.2, CRGB2.2, CRGB3.2, CRGB4.2, CRGB5.2, CRGB6.2, CRGB7.2, CRGB8.2, CRGB9.2, CRGB10.2, CRGB11.2, CRGB12.2, CRGB13.2, CRGB14.2, CRGB15.2, CRGB16.2, CRGB17.2, CRGB18.2, RGB1.3 (VSS), RGB2.3 (VSS), RGB3.3 (VSS), RGB4.3 (VSS), RGB5.3 (VSS), RGB6.3 (VSS), RGB7.3 (VSS), RGB8.3 (VSS), RGB9.3 (VSS), RGB10.3 (VSS), RGB11.3 (VSS), RGB12.3 (VSS), RGB13.3 (VSS), RGB14.3 (VSS), RGB15.3 (VSS), RGB16.3 (VSS), RGB17.3 (VSS), RGB18.3 (VSS); also elsewhere on the board
unnamed: RGB1.2 (DOUT), RGB2.4 (DIN)
unnamed: RGB2.2 (DOUT), RGB3.4 (DIN)
unnamed: RGB3.2 (DOUT), RGB4.4 (DIN)
unnamed: RGB4.2 (DOUT), RGB5.4 (DIN)
unnamed: RGB5.2 (DOUT), RGB6.4 (DIN)
unnamed: RGB6.2 (DOUT), RGB7.4 (DIN)
unnamed: RGB7.2 (DOUT), RGB8.4 (DIN)
unnamed: RGB8.2 (DOUT), RGB9.4 (DIN)
unnamed: RGB10.2 (DOUT), RGB11.4 (DIN)
unnamed: RGB9.2 (DOUT), RGB10.4 (DIN)
unnamed: RGB11.2 (DOUT), RGB12.4 (DIN)
unnamed: RGB12.2 (DOUT), RGB13.4 (DIN)
unnamed: RGB13.2 (DOUT), RGB14.4 (DIN)
unnamed: RGB14.2 (DOUT), RGB15.4 (DIN)
unnamed: RGB15.2 (DOUT), RGB16.4 (DIN)
unnamed: RGB16.2 (DOUT), RGB17.4 (DIN)
unnamed: RGB17.2 (DOUT), RGB18.4 (DIN)
RGBLED: RGB1.4 (DIN); also elsewhere on the board

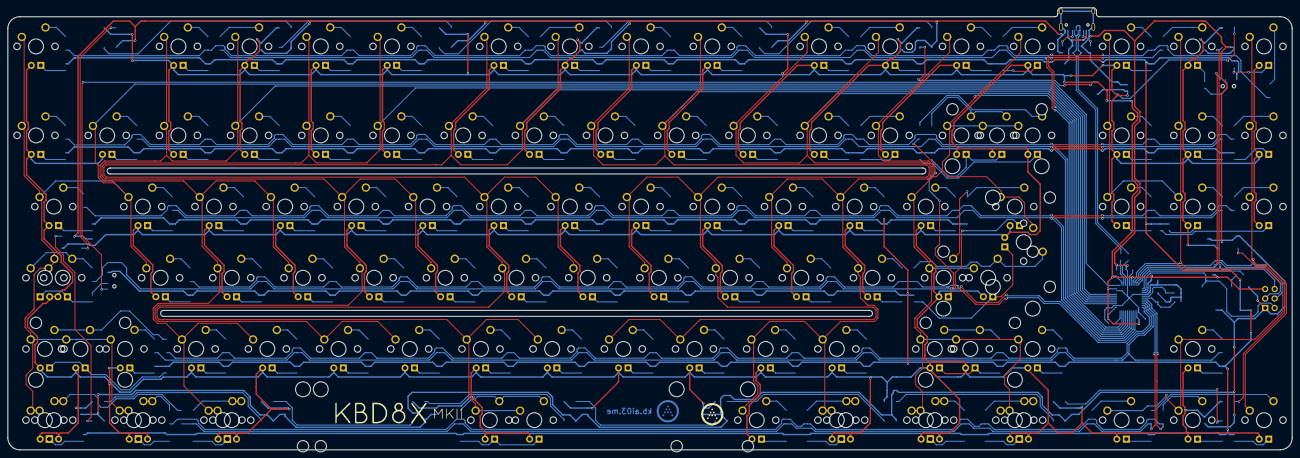
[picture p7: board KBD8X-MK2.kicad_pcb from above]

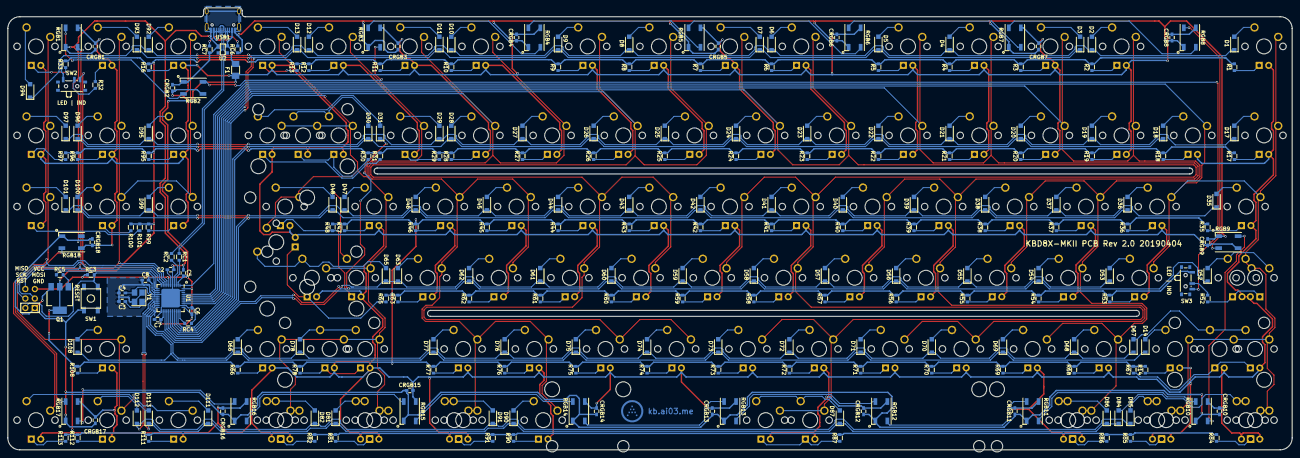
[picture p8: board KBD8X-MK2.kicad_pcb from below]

Board: 2 copper layers, 343.7 x 118.3 mm, 343 parts (240 on the bottom side), 240 nets.

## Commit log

2019-02-07 Temporary progress save
    [Voyager87.kicad_pcb, Voyager87.sch, Voyager87_bom_.csv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]
2019-07-27 Working copy
    [DXP_1921_1.csv.csv, DXP_1921_1.place.csv.csv, KBD8X-MK2.kicad_pcb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]
